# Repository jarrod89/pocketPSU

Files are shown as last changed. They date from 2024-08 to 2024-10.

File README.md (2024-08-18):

# pocketPSU

## Specs  
Output1:  
- Efuse protected USBPD output
- 3A, 20V 
- setting resolution depends on capability of USB-C brickw. If using a PPS capable supply, 10mV CV and 50mA CC settings
- By default this output is disabled as the PD command will track output 3 for minimal power loss in LDO
- Must be lower than output2  
  
Input1:
- Output1 can be used to supply pocketPSU via a battery
- Optional battery charging capability (addon board with BMS)
  
Output2:  
- (optional) Boost output with efuse protection (no dedicated CC)
- 1A 3.3-30V
- By default this tracks output3 for minimal power loss in LDO
- Must be higher than output1 and output3

Output3:  
- LDO output for low ripple
- 1A 0-30V (limited current based on input/output delta)
- Must be lower than output1

### User interface

The user interface will consist of:

- One LCD screen
- One rotary encode + integrated switch. The switch could serve as a way to switch between fine and coarse setting
- One button to turn the power output on/off
- Three buttons for navigation:
  - Up
  - Down
  - Select

### Powering the PSU

The supply can be powered over USB-C or using an external battery. The battery could potentially be a power tool battery that users already have on hand.

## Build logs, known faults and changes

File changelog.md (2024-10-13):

# Changes for hardware V2

- [ ] Move the rotary knob to another position (prevent clash with PSRAM pin)

# PD library to potentially use

- https://github.com/kcl93/fusb302_arduino

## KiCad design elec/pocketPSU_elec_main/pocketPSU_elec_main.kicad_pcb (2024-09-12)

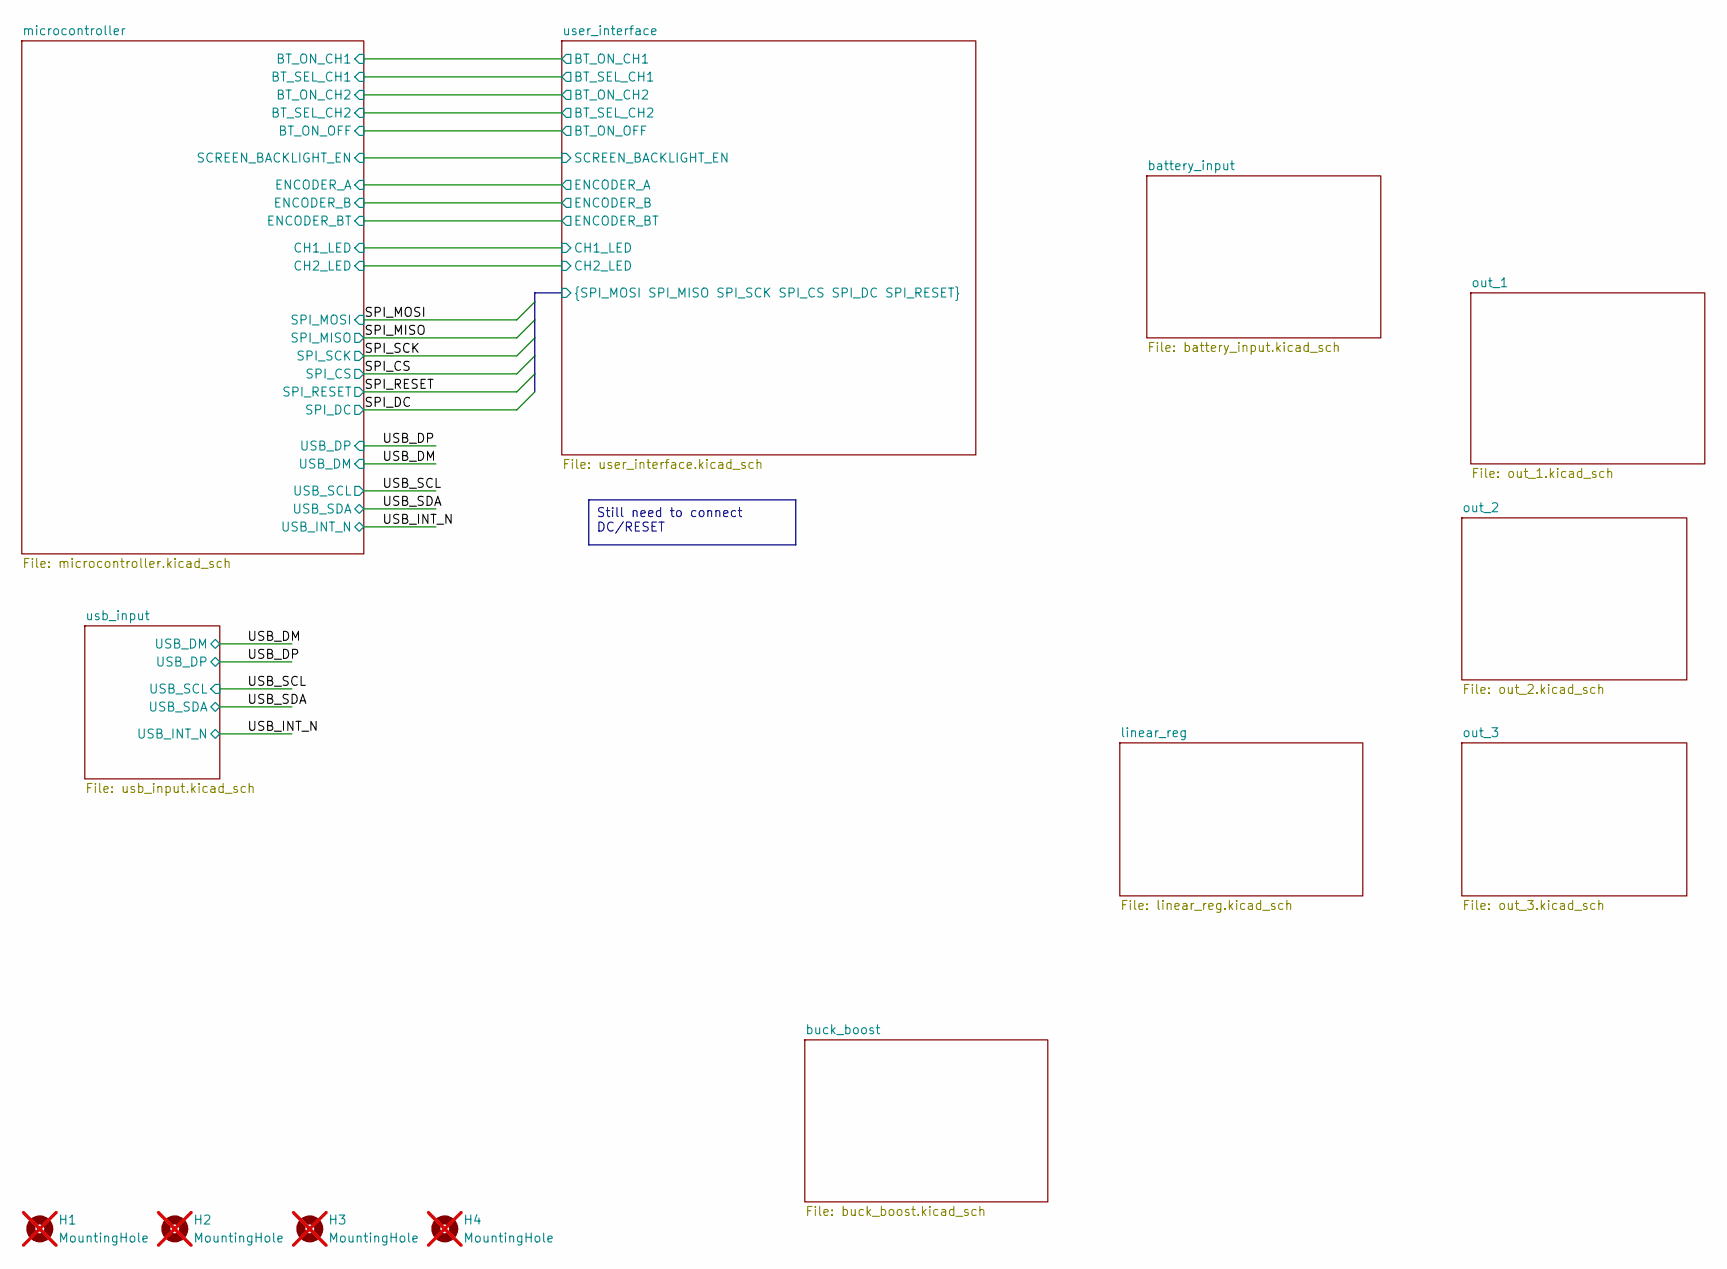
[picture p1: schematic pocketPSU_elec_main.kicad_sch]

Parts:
H1, H2, H3, H4: MountingHole; MountingHole_3.7mm_Pad_Via; not fitted

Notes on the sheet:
Still need to connect DC/RESET

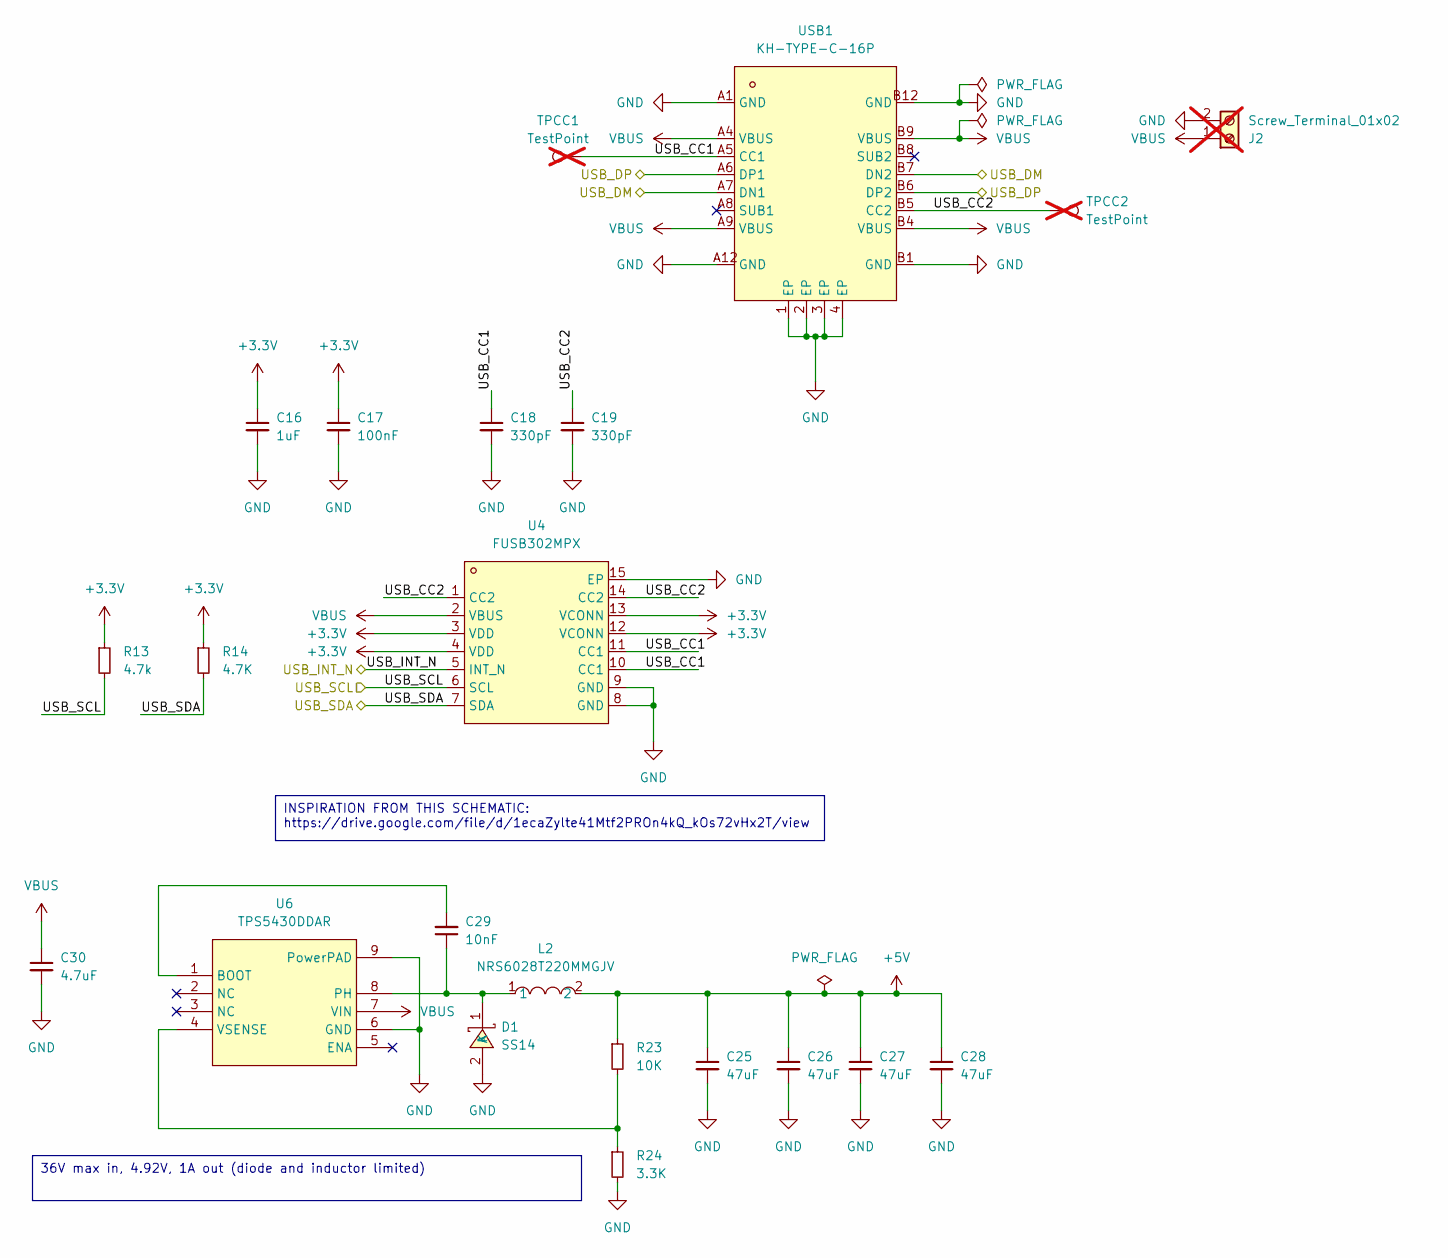
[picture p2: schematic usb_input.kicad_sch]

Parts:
C16: 1uF; C_0805_2012Metric; LCSC Part C28323
C17: 100nF; C_0805_2012Metric; LCSC Part C49678
C18, C19: 330pF; C_0603_1608Metric; LCSC Part C1664
C25, C26, C27, C28: 47uF; C_1206_3216Metric; LCSC Part C96123
C29: 10nF; C_0402_1005Metric; LCSC Part C15195
C30: 4.7uF; C_1206_3216Metric; LCSC Part C29823
D1: SS14; SMA_L4.2-W2.6-LS5.3-RD; LCSC Part C2480
J2: Screw_Terminal_01x02; TerminalBlock_Phoenix_MPT-0,5-2-2.54_1x02_P2.54mm_Horizontal; not fitted
L2: NRS6028T220MMGJV; IND-SMD_L6.0-W6.0; LCSC Part C515357
R13: 4.7k; R_0402_1005Metric; LCSC Part C25900
R14: 4.7K; R_0402_1005Metric; LCSC Part C25900
R23: 10K; R_0402_1005Metric; LCSC Part C25744
R24: 3.3K; R_0402_1005Metric; LCSC Part C25890
TPCC1, TPCC2: TestPoint; TestPoint_Pad_D1.5mm; not fitted
U4: FUSB302MPX; MLP-14_L2.5-W2.5-P0.50-BL-EP; LCSC Part C442699
U6: TPS5430DDAR; ESOP-8_L4.9-W3.9-P1.27-LS6.0-TL-EP; LCSC Part C9864
USB1: KH-TYPE-C-16P; USB-C-SMD_KH-TYPE-C-16P; LCSC Part C709357

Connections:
+3.3V: C16.1, C17.1, R13.1, R14.1, U4.3 (VDD), U4.4 (VDD), U4.12 (VCONN), U4.13 (VCONN); also elsewhere on the board
+5V: C25.1, C26.1, C27.1, C28.1, L2.2, R23.1; also elsewhere on the board
/USB_DM: USB1.A7 (DN1), USB1.B7 (DN2); also elsewhere on the board
/USB_DP: USB1.A6 (DP1), USB1.B6 (DP2); also elsewhere on the board
/USB_INT_N: U4.5 (INT_N); also elsewhere on the board
/USB_SCL: R13.2, U4.6 (SCL); also elsewhere on the board
/USB_SDA: R14.2, U4.7 (SDA); also elsewhere on the board
/usb_input/USB_CC1: C18.1, TPCC1.1, U4.10 (CC1), U4.11 (CC1), USB1.A5 (CC1)
/usb_input/USB_CC2: C19.1, TPCC2.1, U4.1 (CC2), U4.14 (CC2), USB1.B5 (CC2)
GND: C16.2, C17.2, C18.2, C19.2, C25.2, C26.2, C27.2, C28.2, C30.2, D1.2 (A), J2.2, R24.2, U4.8 (GND), U4.9 (GND), U4.15 (EP), U6.6 (GND), U6.9 (PowerPAD), USB1.1 (EP), USB1.2 (EP), USB1.3 (EP), USB1.4 (EP), USB1.A1 (GND), USB1.A12 (GND), USB1.B1 (GND), USB1.B12 (GND); also elsewhere on the board
unnamed: C29.1, D1.1 (K), L2.1, U6.8 (PH)
unnamed: C29.2, U6.1 (BOOT)
unnamed: R23.2, R24.1, U6.4 (VSENSE)
VBUS: C30.1, J2.1, U4.2 (VBUS), U6.7 (VIN), USB1.A4 (VBUS), USB1.A9 (VBUS), USB1.B4 (VBUS), USB1.B9 (VBUS)

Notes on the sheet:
36V max in, 4.92V, 1A out (diode and inductor limited)
INSPIRATION FROM THIS SCHEMATIC: https://drive.google.com/file/d/1ecaZylte41Mtf2PROn4kQ_kOs72vHx2T/view

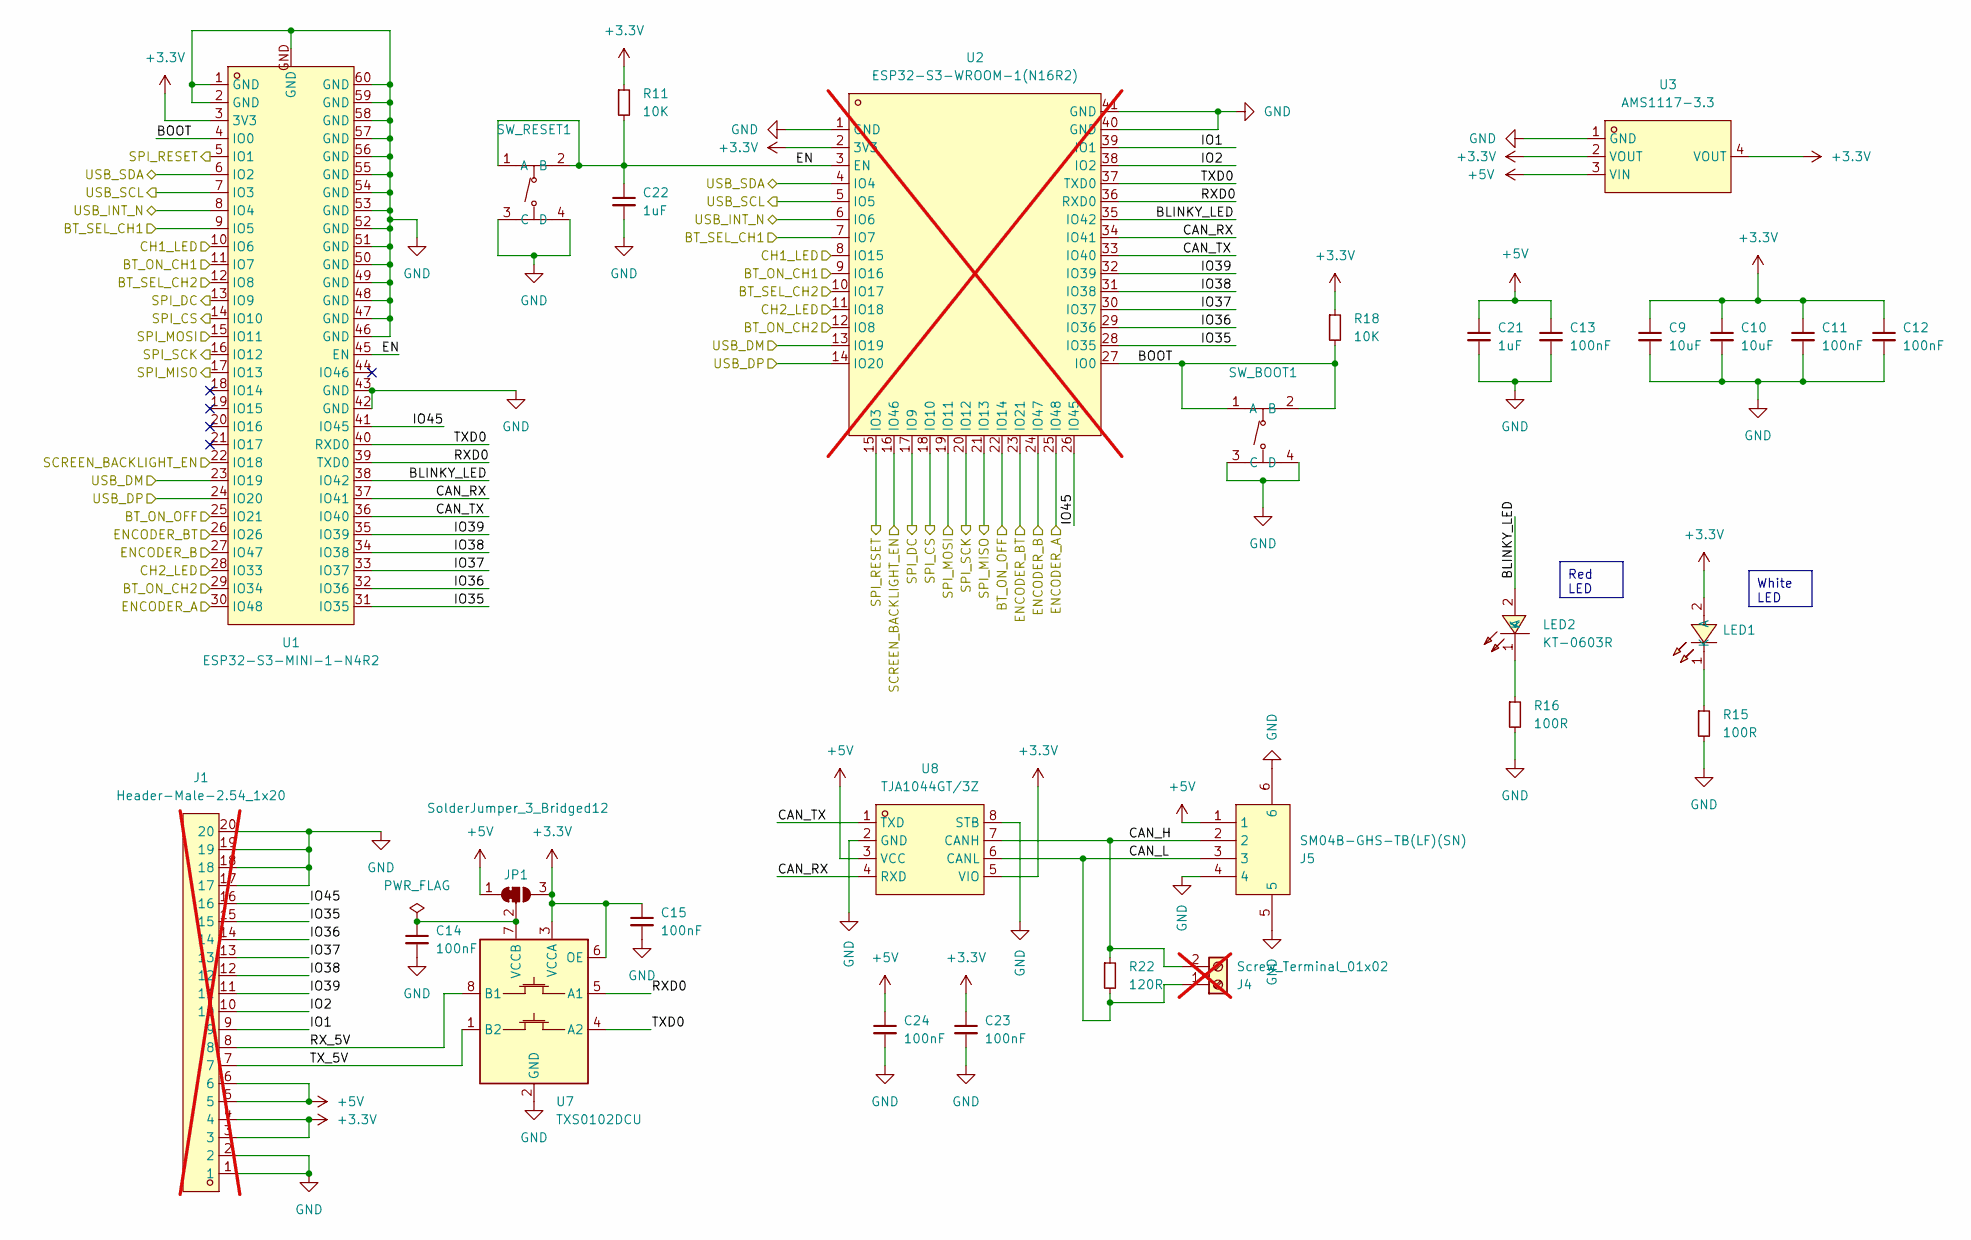
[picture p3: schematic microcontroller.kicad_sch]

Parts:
C9, C10: 10uF; C_0805_2012Metric; LCSC Part C15850
C11, C12, C13, C14, C15, C23, C24: 100nF; C_0805_2012Metric; LCSC Part C49678
C21, C22: 1uF; R_0805_2012Metric; LCSC Part C28323
J1: Header-Male-2.54_1x20; HDR-TH_20P-P2.54-V-M-1; LCSC Part C50981; not fitted
J4: Screw_Terminal_01x02; TerminalBlock_Phoenix_MPT-0,5-2-2.54_1x02_P2.54mm_Horizontal; not fitted
J5: SM04B-GHS-TB(LF)(SN); CONN-SMD_4P-P1.25_SM04B-GHS-TB-LF-SN; LCSC Part C189895
JP1: SolderJumper_3_Bridged12; SolderJumper-3_P1.3mm_Bridged12_RoundedPad1.0x1.5mm_NumberL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
LED1: F.0603.00026/P2-0603B1TS2-06T-001; LED0603-RD; LCSC Part C2290
LED2: KT-0603R; LED0603-RD; LCSC Part C2286
R11, R18: 10K; R_0402_1005Metric; LCSC Part C25744
R15, R16: 100R; R_0402_1005Metric; LCSC Part C25076
R22: 120R; R_0603_1608Metric; LCSC Part C22787
SW_BOOT1: TS-1187A-B-A-B; SW-SMD_4P-L5.1-W5.1-P3.70-LS6.5-TL-2; LCSC Part C318884
SW_RESET1: TS-1187A-B-A-B; SW-SMD_4P-L5.1-W5.1-P3.70-LS6.5-TL-2; LCSC Part C318884
U1: ESP32-S3-MINI-1-N4R2; BULETM-SMD_ESP32-S3-MINI-1-N8; LCSC Part C3013941
U2: ESP32-S3-WROOM-1(N16R2); WIRELM-SMD_ESP32-S3-WROOM-1; LCSC Part C2913205; not fitted
U3: AMS1117-3.3; SOT-223-3_L6.5-W3.4-P2.30-LS7.0-BR; LCSC Part C6186
U7: TXS0102DCU; VSSOP-8_2.3x2mm_P0.5mm; LCSC Part C53434
U8: TJA1044GT/3Z; SO-8_L4.9-W3.9-P1.27-LS5.9-BL; LCSC Part C961486

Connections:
+3.3V: C9.1, C10.1, C11.1, C12.1, C15.1, C23.1, J1.3, J1.4, JP1.3 (B), LED1.2 (A), R11.1, R18.1, U1.3 (3V3), U2.2 (3V3), U3.2 (VOUT), U3.4 (VOUT), U7.3 (VCCA), U7.6 (OE), U8.5 (VIO); also elsewhere on the board
+5V: C13.1, C21.1, C24.1, J1.5, J1.6, J5.1, JP1.1 (A), U3.3 (VIN), U8.3 (VCC); also elsewhere on the board
/USB_DM: U1.23 (IO19), U2.13 (IO19); also elsewhere on the board
/USB_DP: U1.24 (IO20), U2.14 (IO20); also elsewhere on the board
/USB_INT_N: U1.8 (IO4), U2.6 (IO6); also elsewhere on the board
/USB_SCL: U1.7 (IO3), U2.5 (IO5); also elsewhere on the board
/USB_SDA: U1.6 (IO2), U2.4 (IO4); also elsewhere on the board
/microcontroller/BLINKY_LED: LED2.2 (A), U1.38 (IO42), U2.35 (IO42)
/microcontroller/BOOT: R18.2, SW_BOOT1.1 (A), SW_BOOT1.2 (B), U1.4 (IO0), U2.27 (IO0)
/microcontroller/BT_ON_CH1: U1.11 (IO7), U2.9 (IO16); also elsewhere on the board
/microcontroller/BT_ON_CH2: U1.29 (IO34), U2.12 (IO8); also elsewhere on the board
/microcontroller/BT_ON_OFF: U1.25 (IO21), U2.22 (IO14); also elsewhere on the board
/microcontroller/BT_SEL_CH1: U1.9 (IO5), U2.7 (IO7); also elsewhere on the board
/microcontroller/BT_SEL_CH2: U1.12 (IO8), U2.10 (IO17); also elsewhere on the board
/microcontroller/CAN_H: J4.2, J5.2, R22.1, U8.7 (CANH)
/microcontroller/CAN_L: J4.1, J5.3, R22.2, U8.6 (CANL)
/microcontroller/CAN_RX: U1.37 (IO41), U2.34 (IO41), U8.4 (RXD)
/microcontroller/CAN_TX: U1.36 (IO40), U2.33 (IO40), U8.1 (TXD)
/microcontroller/CH1_LED: U1.10 (IO6), U2.8 (IO15); also elsewhere on the board
/microcontroller/CH2_LED: U1.28 (IO33), U2.11 (IO18); also elsewhere on the board
/microcontroller/EN: C22.1, R11.2, SW_RESET1.1 (A), SW_RESET1.2 (B), U1.45 (EN), U2.3 (EN)
/microcontroller/ENCODER_A: U1.30 (IO48), U2.25 (IO48); also elsewhere on the board
/microcontroller/ENCODER_B: U1.27 (IO47), U2.24 (IO47); also elsewhere on the board
/microcontroller/ENCODER_BT: U1.26 (IO26), U2.23 (IO21); also elsewhere on the board
/microcontroller/IO1: J1.9, U2.39 (IO1)
/microcontroller/IO2: J1.10, U2.38 (IO2)
/microcontroller/IO35: J1.15, U1.31 (IO35), U2.28 (IO35)
/microcontroller/IO36: J1.14, U1.32 (IO36), U2.29 (IO36)
/microcontroller/IO37: J1.13, U1.33 (IO37), U2.30 (IO37)
/microcontroller/IO38: J1.12, U1.34 (IO38), U2.31 (IO38)
/microcontroller/IO39: J1.11, U1.35 (IO39), U2.32 (IO39)
/microcontroller/IO45: J1.16, U1.41 (IO45), U2.26 (IO45)
/microcontroller/RXD0: U1.39 (TXD0), U2.36 (RXD0), U7.5 (A1)
/microcontroller/RX_5V: J1.8, U7.8 (B1)
/microcontroller/TXD0: U1.40 (RXD0), U2.37 (TXD0), U7.4 (A2)
/microcontroller/TX_5V: J1.7, U7.1 (B2)
/user_interface/BACKLIGHT_EN: U1.22 (IO18), U2.16 (IO46); also elsewhere on the board
/user_interface/SPI_CS: U1.14 (IO10), U2.18 (IO10); also elsewhere on the board
/user_interface/SPI_DC: U1.13 (IO9), U2.17 (IO9); also elsewhere on the board
/user_interface/SPI_MISO: U1.17 (IO13), U2.21 (IO13); also elsewhere on the board
/user_interface/SPI_MOSI: U1.15 (IO11), U2.19 (IO11); also elsewhere on the board
/user_interface/SPI_RESET: U1.5 (IO1), U2.15 (IO3); also elsewhere on the board
/user_interface/SPI_SCK: U1.16 (IO12), U2.20 (IO12); also elsewhere on the board
GND: C9.2, C10.2, C11.2, C12.2, C13.2, C14.2, C15.2, C21.2, C22.2, C23.2, C24.2, J1.1, J1.2, J1.17, J1.18, J1.19, J1.20, J5.4, J5.5, J5.6, R15.2, R16.2, SW_BOOT1.3 (C), SW_BOOT1.4 (D), SW_RESET1.3 (C), SW_RESET1.4 (D), U1.1 (GND), U1.2 (GND), U1.42 (GND), U1.43 (GND), U1.46 (GND), U1.47 (GND), U1.48 (GND), U1.49 (GND), U1.50 (GND), U1.51 (GND), U1.52 (GND), U1.53 (GND), U1.54 (GND), U1.55 (GND), U1.56 (GND), U1.57 (GND), U1.58 (GND), U1.59 (GND), U1.60 (GND), U1.GND, U2.1 (GND), U2.40 (GND), U2.41 (GND), U3.1 (GND), U7.2 (GND), U8.2 (GND), U8.8 (STB); also elsewhere on the board
unnamed: C14.1, JP1.2 (C), U7.7 (VCCB)
unnamed: LED1.1 (K), R15.1
unnamed: LED2.1 (K), R16.1

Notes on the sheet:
White LED
Red LED

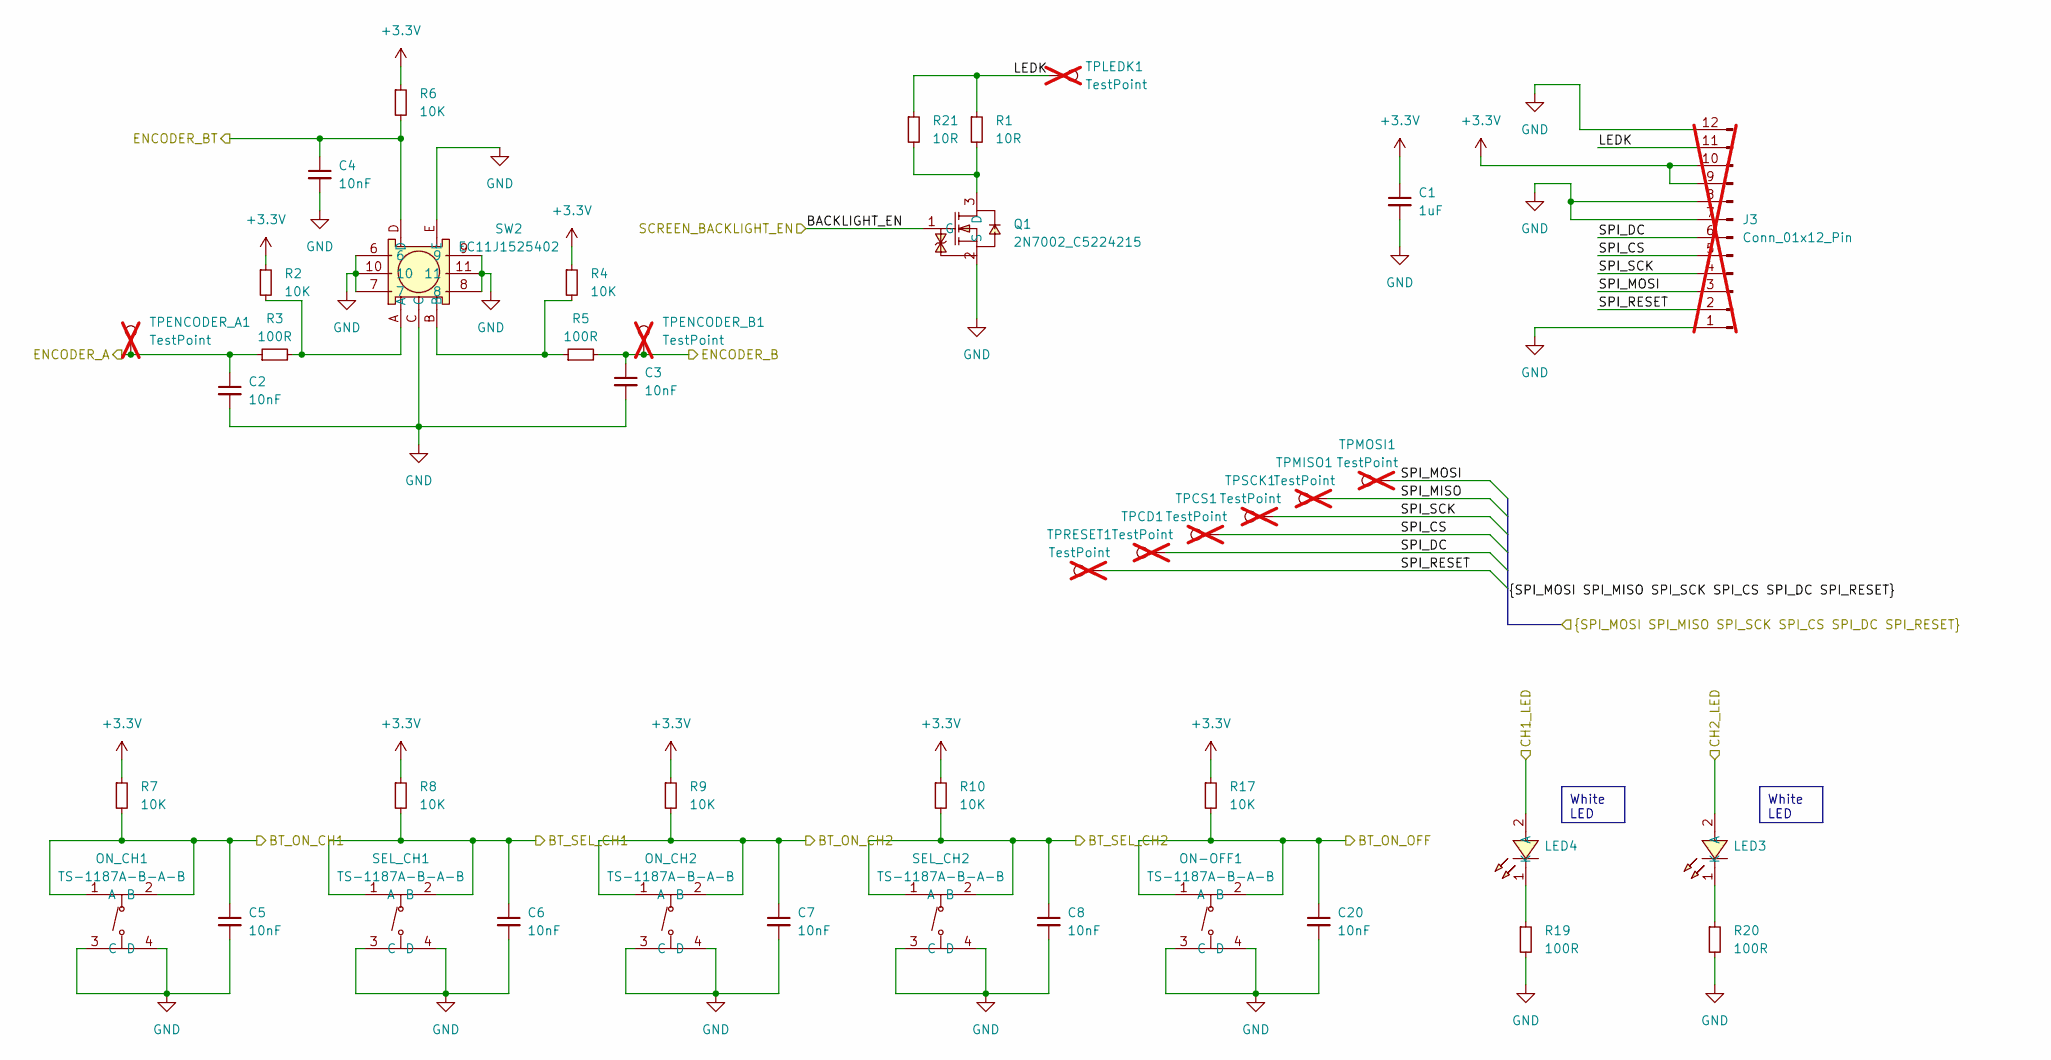
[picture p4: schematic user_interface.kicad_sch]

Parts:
C1: 1uF; R_0805_2012Metric; LCSC Part C28323
C2, C3, C4, C5, C6, C7, C8, C20: 10nF; C_0402_1005Metric; LCSC Part C15195
J3: Conn_01x12_Pin; LCD-GMT020-02; not fitted
LED3, LED4: F.0603.00026/P2-0603B1TS2-06T-001; LED0603-RD; LCSC Part C2290
ON-OFF1: TS-1187A-B-A-B; SW-SMD_4P-L5.1-W5.1-P3.70-LS6.5-TL-2; LCSC Part C318884
ON_CH1, ON_CH2: TS-1187A-B-A-B; SW-SMD_4P-L5.1-W5.1-P3.70-LS6.5-TL-2; LCSC Part C318884
Q1: 2N7002_C5224215; SOT-23-3_L3.0-W1.6-P1.90-LS2.8-BR; LCSC Part C5224215
R1, R21: 10R; R_0402_1005Metric; LCSC Part C25077
R2, R4, R6, R7, R8, R9, R10, R17: 10K; R_0402_1005Metric; LCSC Part C25744
R3, R5, R19, R20: 100R; R_0402_1005Metric; LCSC Part C25076
SEL_CH1, SEL_CH2: TS-1187A-B-A-B; SW-SMD_4P-L5.1-W5.1-P3.70-LS6.5-TL-2; LCSC Part C318884
SW2: EC11J1525402; SW-SMD_EC11J1525402; LCSC Part C209762
TPCD1: TestPoint; TestPoint_Pad_D1.5mm; not fitted
TPCS1: TestPoint; TestPoint_Pad_D1.5mm; not fitted
TPENCODER_A1: TestPoint; TestPoint_Pad_D1.5mm; not fitted
TPENCODER_B1: TestPoint; TestPoint_Pad_D1.5mm; not fitted
TPLEDK1: TestPoint; TestPoint_Pad_D1.5mm; not fitted
TPMISO1: TestPoint; TestPoint_Pad_D1.5mm; not fitted
TPMOSI1: TestPoint; TestPoint_Pad_D1.5mm; not fitted
TPRESET1: TestPoint; TestPoint_Pad_D1.5mm; not fitted
TPSCK1: TestPoint; TestPoint_Pad_D1.5mm; not fitted

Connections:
+3.3V: C1.1, J3.9, J3.10, R2.1, R4.1, R6.1, R7.1, R8.1, R9.1, R10.1, R17.1; also elsewhere on the board
/microcontroller/BT_ON_CH1: C5.1, ON_CH1.1 (A), ON_CH1.2 (B), R7.2; also elsewhere on the board
/microcontroller/BT_ON_CH2: C7.1, ON_CH2.1 (A), ON_CH2.2 (B), R9.2; also elsewhere on the board
/microcontroller/BT_ON_OFF: C20.1, ON-OFF1.1 (A), ON-OFF1.2 (B), R17.2; also elsewhere on the board
/microcontroller/BT_SEL_CH1: C6.1, R8.2, SEL_CH1.1 (A), SEL_CH1.2 (B); also elsewhere on the board
/microcontroller/BT_SEL_CH2: C8.1, R10.2, SEL_CH2.1 (A), SEL_CH2.2 (B); also elsewhere on the board
/microcontroller/CH1_LED: LED4.2 (A); also elsewhere on the board
/microcontroller/CH2_LED: LED3.2 (A); also elsewhere on the board
/microcontroller/ENCODER_A: C2.1, R3.1, TPENCODER_A1.1; also elsewhere on the board
/microcontroller/ENCODER_B: C3.1, R5.2, TPENCODER_B1.1; also elsewhere on the board
/microcontroller/ENCODER_BT: C4.1, R6.2, SW2.D; also elsewhere on the board
/user_interface/BACKLIGHT_EN: Q1.1 (G); also elsewhere on the board
/user_interface/LEDK: J3.11, R1.1, R21.1, TPLEDK1.1
/user_interface/SPI_CS: J3.5, TPCS1.1; also elsewhere on the board
/user_interface/SPI_DC: J3.6, TPCD1.1; also elsewhere on the board
/user_interface/SPI_MISO: TPMISO1.1; also elsewhere on the board
/user_interface/SPI_MOSI: J3.3, TPMOSI1.1; also elsewhere on the board
/user_interface/SPI_RESET: J3.2, TPRESET1.1; also elsewhere on the board
/user_interface/SPI_SCK: J3.4, TPSCK1.1; also elsewhere on the board
GND: C1.2, C2.2, C3.2, C4.2, C5.2, C6.2, C7.2, C8.2, C20.2, J3.1, J3.7, J3.8, J3.12, ON-OFF1.3 (C), ON-OFF1.4 (D), ON_CH1.3 (C), ON_CH1.4 (D), ON_CH2.3 (C), ON_CH2.4 (D), Q1.2 (S), R19.2, R20.2, SEL_CH1.3 (C), SEL_CH1.4 (D), SEL_CH2.3 (C), SEL_CH2.4 (D), SW2.6, SW2.7, SW2.8, SW2.9, SW2.10, SW2.11, SW2.C, SW2.E; also elsewhere on the board
unnamed: LED3.1 (K), R20.1
unnamed: LED4.1 (K), R19.1
unnamed: Q1.3 (D), R1.2, R21.2
unnamed: R2.2, R3.2, SW2.A
unnamed: R4.2, R5.1, SW2.B

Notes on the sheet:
White LED

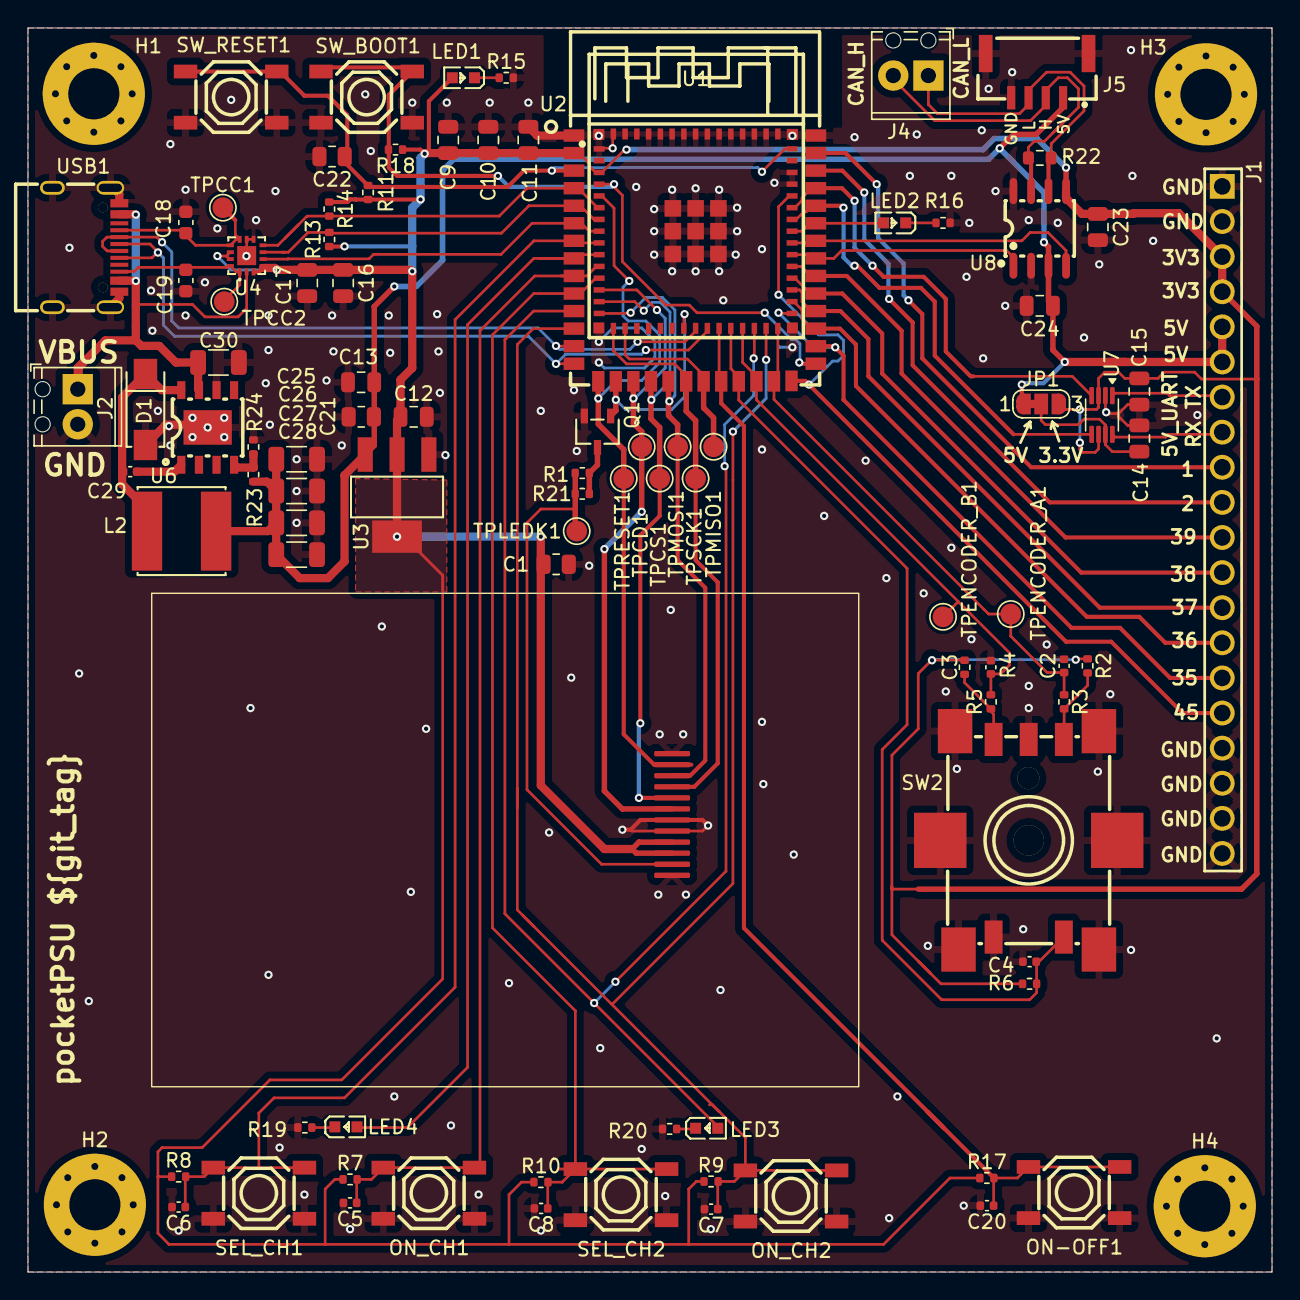
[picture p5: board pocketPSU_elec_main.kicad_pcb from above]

Board: 2 copper layers, 90.0 x 90.0 mm, 97 parts (0 on the bottom side), 59 nets.

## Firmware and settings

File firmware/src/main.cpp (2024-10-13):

#include <Arduino.h>
#include <ESP32-TWAI-CAN.hpp>
#include <lvgl.h>
#if LV_USE_TFT_ESPI
#include <TFT_eSPI.h>
#endif

#include <Wire.h>
#include <PD_UFP.h>

#define PIN_FUSB302_INT   4

class PD_UFP_Log_c PD_UFP;

#define SERIAL_DEBUG 1

#include "StateMachine.hpp"

#define TFT_HOR_RES   240
#define TFT_VER_RES   320
#define TFT_ROTATION  LV_DISPLAY_ROTATION_270

#define SDA_PIN 2
#define SCL_PIN 3


// /*LVGL draw into this buffer, 1/10 screen size usually works well. The size is in bytes*/
// #define DRAW_BUF_SIZE (TFT_HOR_RES * TFT_VER_RES / 10 * (LV_COLOR_DEPTH / 8))
// uint32_t draw_buf[DRAW_BUF_SIZE / 4];

// /* LVGL calls it when a rendered image needs to copied to the display*/
// void my_disp_flush( lv_display_t *disp, const lv_area_t *area, uint8_t * px_map)
// {
//     /*Call it to tell LVGL you are ready*/
//     lv_display_flush_ready(disp);
// }

// /*use Arduinos millis() as tick source*/
// static uint32_t my_tick(void)
// {
//     return millis();
// }


// StateMachine state_machine;

// float voltage_limit_ch1;
// float current_limit_ch1;
// float voltage_limit_ch2;
// float current_limit_ch2;
// float voltage_ch1;
// float current_ch1;
// float power_ch1;
// float voltage_ch2;
// float current_ch2;
// float power_ch2;

// lv_obj_t *voltage_limit_ch1_label;
// lv_obj_t *current_limit_ch1_label;
// lv_obj_t *voltage_limit_ch2_label;
// lv_obj_t *current_limit_ch2_label;
// lv_obj_t *voltage_ch1_label;
// lv_obj_t *current_ch1_label;
// lv_obj_t *power_ch1_label;
// lv_obj_t *voltage_ch2_label;
// lv_obj_t *current_ch2_label;
// lv_obj_t *power_ch2_label;

// static lv_style_t style_normal;
// static lv_style_t style_active;


// volatile long encoderCtr = 0;

// void handleEncoder() {
//     if(digitalRead(ENCODER_A))
//     {
//         if(digitalRead(ENCODER_B))
//         encoderCtr++;
//         else
//         encoderCtr--;
//     }
//     else
//     {
//         if(digitalRead(ENCODER_B))
//         encoderCtr--;
//         else
//         encoderCtr++;
//     }
// }
// volatile unsigned long lastDebounceTimeCh1Set = 0;  // Variables to store last debounce time
// volatile unsigned long lastDebounceTimeCh2Set = 0;
// volatile unsigned long lastDebounceTimeCh1On = 0;
// volatile unsigned long lastDebounceTimeCh2On = 0;
// volatile unsigned long lastDebounceTimeOnOff = 0;

// const unsigned long debounceDelay = 200;  // Set debounce delay to 50ms

// void handleCh1SetBt() {
//     if ((millis() - lastDebounceTimeCh1Set) > debounceDelay) {
//         lastDebounceTimeCh1Set = millis();  // Update last debounce time
//         state_machine.handleCh1SetBt();  // Your existing function
//     }
// }

// void handleCh2SetBt() {
//     if ((millis() - lastDebounceTimeCh2Set) > debounceDelay) {
//         lastDebounceTimeCh2Set = millis();
//         state_machine.handleCh2SetBt();
//     }
// }

// void handleCh1OnBt() {
//     if ((millis() - lastDebounceTimeCh1On) > debounceDelay) {
//         lastDebounceTimeCh1On = millis();
//         state_machine.handleCh1OnBt();  // Call your state handling logic
//     }
// }

// void handleCh2OnBt() {
//     if ((millis() - lastDebounceTimeCh2On) > debounceDelay) {
//         lastDebounceTimeCh2On = millis();
//         state_machine.handleCh2OnBt();
//     }
// }

// void handleOnOffBt() {
//     if ((millis() - lastDebounceTimeOnOff) > debounceDelay) {
//         lastDebounceTimeOnOff = millis();
//         digitalWrite(LED_RED, !digitalRead(LED_RED));  // Toggle LED state
//     }
// }

// // void handleKnobBt() {
// //     digitalWrite(LED_RED, !digitalRead(LED_RED));  // Toggle LED state
// // }

// void highlight_active_label(lv_obj_t *label) {
//   // Apply the active style (black background, white text)
//   lv_obj_add_style(label, &style_active, LV_PART_MAIN);
// }

// // remove the highlight after update
// void remove_highlights() {
//     lv_obj_add_style(voltage_limit_ch1_label, &style_normal, LV_PART_MAIN);
//     lv_obj_add_style(current_limit_ch1_label, &style_normal, LV_PART_MAIN);
//     lv_obj_add_style(voltage_limit_ch2_label, &style_normal, LV_PART_MAIN);
//     lv_obj_add_style(current_limit_ch2_label, &style_normal, LV_PART_MAIN);
// }



void setup() {
    pinMode(LED_RED, OUTPUT);
    digitalWrite(LED_RED, 1);
    delay(100);
    // pinMode(LED_CH1, OUTPUT);
    // pinMode(LED_CH2, OUTPUT);

    // pinMode(CH_1_SET_BT, INPUT_PULLUP);
    // pinMode(CH_2_SET_BT, INPUT_PULLUP);
    // pinMode(CH_1_ON_BT, INPUT_PULLUP);
    // pinMode(CH_2_ON_BT, INPUT_PULLUP);
    // pinMode(ALL_ON_OFF, INPUT_PULLUP);
    // // pinMode(KNOB_BT, INPUT);
    // pinMode(ENCODER_A, INPUT);
    // pinMode(ENCODER_B, INPUT);
    // attachInterrupt(digitalPinToInterrupt(ENCODER_A), handleEncoder,CHANGE);
    // attachInterrupt(digitalPinToInterrupt(CH_1_SET_BT), handleCh1SetBt, FALLING);
    // attachInterrupt(digitalPinToInterrupt(CH_2_SET_BT), handleCh2SetBt, FALLING);
    // attachInterrupt(digitalPinToInterrupt(CH_1_ON_BT), handleCh1OnBt, FALLING);
    // attachInterrupt(digitalPinToInterrupt(CH_2_ON_BT), handleCh2OnBt, FALLING);
    // attachInterrupt(digitalPinToInterrupt(ALL_ON_OFF), handleOnOffBt, FALLING);
    // attachInterrupt(digitalPinToInterrupt(KNOB_BT), handleKnobBt, FALLING);

    #if SERIAL_DEBUG
    // Setup serial for debbuging.
    Serial.begin(115200);
    // tft.println("Hello World!");
    Serial.println("Hello World!");
    #endif

    // Setup UART0 for debugging
    Serial0.begin(115200);
    Serial0.println("Startup");

    Wire.begin(SDA_PIN, SCL_PIN, 100000);
    PD_UFP.init(PIN_FUSB302_INT, PD_POWER_OPTION_MAX_9V);
    // PD_UFP.init_PPS(PIN_FUSB302_INT, PPS_V(5.5), PPS_A(.5));
    PD_UFP.init_PPS(PIN_FUSB302_INT, PPS_V(9.0), PPS_A(5.0));

    // // //Initialize the LVGL library
    // lv_init();

    // /*Set a tick source so that LVGL will know how much time elapsed. */
    // lv_tick_set_cb(my_tick);

    // lv_style_init(&style_normal);
    // lv_style_set_bg_opa(&style_normal, LV_OPA_TRANSP);  // No background
    // lv_style_set_text_color(&style_normal, lv_color_hex(0x000000));  // White text

    // lv_style_init(&style_active);
    // lv_style_set_bg_opa(&style_active, LV_OPA_COVER);  // Opaque background
    // lv_style_set_bg_color(&style_active, lv_color_hex(0x000000));  // Black background
    // lv_style_set_text_color(&style_active, lv_color_hex(0xFFFFFF));  // White text

    // // alternative function: lv_obj_set_style_text_color(thing, lv_color_black(), LV_PART_MAIN);


    // lv_display_t * disp;
    // /*TFT_eSPI can be enabled lv_conf.h to initialize the display in a simple way*/
    // disp = lv_tft_espi_create(TFT_HOR_RES, TFT_VER_RES, draw_buf, sizeof(draw_buf));
    // lv_display_set_rotation(disp, TFT_ROTATION);

    // // Initialize the labels on screen
    // // CH1
    // voltage_ch1_label = lv_label_create(lv_scr_act());
    // lv_label_set_text_fmt(voltage_ch1_label, "%.3fV", voltage_ch1);
    // lv_obj_align(voltage_ch1_label, LV_ALIGN_TOP_LEFT, 10, 50);

    // current_ch1_label = lv_label_create(lv_scr_act());
    // lv_label_set_text_fmt(current_ch1_label, "%.3fV", current_ch1);
    // lv_obj_align(current_ch1_label, LV_ALIGN_TOP_LEFT, 10, 80);

    // lv_obj_t *set_txt_ch1 = lv_label_create(lv_scr_act());
    // lv_label_set_text(set_txt_ch1, "set");
    // lv_obj_align(set_txt_ch1, LV_ALIGN_TOP_LEFT, 5, 200);

    // voltage_limit_ch1_label = lv_label_create(lv_scr_act());
    // lv_label_set_text_fmt(voltage_limit_ch1_label, "%fV", voltage_limit_ch1);
    // lv_obj_align(voltage_limit_ch1_label, LV_ALIGN_TOP_LEFT, 30, 200);

    // current_limit_ch1_label = lv_label_create(lv_scr_act());
    // lv_label_set_text_fmt(current_limit_ch1_label, "%fA", current_limit_ch1);
    // lv_obj_align(current_limit_ch1_label, LV_ALIGN_TOP_LEFT, 90, 200);

    // // CH2

    // voltage_ch2_label = lv_label_create(lv_scr_act());
    // lv_label_set_text_fmt(voltage_ch2_label, "%fV", voltage_ch2);
    // lv_obj_align(voltage_ch2_label, LV_ALIGN_TOP_LEFT, 170, 50);

    // current_ch2_label = lv_label_create(lv_scr_act());
    // lv_label_set_text_fmt(current_ch2_label, "%fV", current_ch2);
    // lv_obj_align(current_ch2_label, LV_ALIGN_TOP_LEFT, 170, 80);

    // lv_obj_t *set_txt_ch2 = lv_label_create(lv_scr_act());
    // lv_label_set_text(set_txt_ch2, "set");
    // lv_obj_align(set_txt_ch2, LV_ALIGN_TOP_LEFT, 165, 200);

    // voltage_limit_ch2_label = lv_label_create(lv_scr_act());
    // lv_label_set_text_fmt(voltage_limit_ch2_label, "%fV", voltage_limit_ch2);
    // lv_obj_align(voltage_limit_ch2_label, LV_ALIGN_TOP_LEFT, 190, 200);  // Position the label

    // current_limit_ch2_label = lv_label_create(lv_scr_act());
    // lv_label_set_text_fmt(current_limit_ch2_label, "%fA", current_limit_ch2);
    // lv_obj_align(current_limit_ch2_label, LV_ALIGN_TOP_LEFT, 250, 200);  // Position the label

    // // CH2

    // voltage_limit_ch2_label = lv_label_create(lv_scr_act());
    // lv_label_set_text_fmt(voltage_limit_ch2_label, "Voltage ch2: %d V", voltage_limit_ch2);
    // lv_obj_align(voltage_limit_ch2_label, LV_ALIGN_TOP_LEFT, 160, 10);  // Position the label

    // current_limit_ch2_label = lv_label_create(lv_scr_act());
    // lv_label_set_text_fmt(current_limit_ch2_label, "Current ch2: %d A", current_limit_ch2);
    // lv_obj_align(current_limit_ch2_label, LV_ALIGN_TOP_LEFT, 160, 40);  // Position the label
}

void loop() {

    // StateStruct currentState = state_machine.getState();
    // switch (currentState.settingState) {
    //     case SettingState::IDLE:
    //         #if SERIAL_DEBUG
    //         Serial.println("IDLE");
    //         #endif
    //         // flush the encoder values
    //         encoderCtr = 0;
    //         remove_highlights();
    //         break;
    //     case SettingState::SET_VOLTAGE_CH_1:
    //         #if SERIAL_DEBUG
    //         Serial.print("SET_VOLTAGE_CH_1: ");
    //         Serial.println(voltage_limit_ch1);
    //         #endif
    //         voltage_limit_ch1 += encoderCtr;
    //         encoderCtr = 0;
    //         remove_highlights();
    //         highlight_active_label(voltage_limit_ch1_label);
    //         break;
    //     case SettingState::SET_CURRENT_CH_1:
    //         #if SERIAL_DEBUG
    //         Serial.print("SET_CURRENT_CH_1: ");
    //         Serial.println(current_limit_ch1);
    //         #endif
    //         current_limit_ch1 += encoderCtr;
    //         encoderCtr = 0;
    //         remove_highlights();
    //         highlight_active_label(current_limit_ch1_label);
    //         break;
    //     case SettingState::SET_VOLTAGE_CH_2:
    //         #if SERIAL_DEBUG
    //         Serial.print("SET_VOLTAGE_CH_2: ");
    //         Serial.println(voltage_limit_ch2);
    //         #endif
    //         voltage_limit_ch2 += encoderCtr;
    //         encoderCtr = 0;
    //         remove_highlights();
    //         highlight_active_label(voltage_limit_ch2_label);
    //         break;
    //     case SettingState::SET_CURRENT_CH_2:
    //         #if SERIAL_DEBUG
    //         Serial.print("SET_CURRENT_CH_2: ");
    //         Serial.println(current_limit_ch2);
    //         #endif
    //         current_limit_ch2 += encoderCtr;
    //         encoderCtr = 0;
    //         remove_highlights();
    //         highlight_active_label(current_limit_ch2_label);
    //         break;
    // }
    // switch (currentState.channel1State) {
    //     case ChannelState::IDLE:
    //         digitalWrite(LED_CH1, LOW);
    //         break;
    //     case ChannelState::ON:
    //         digitalWrite(LED_CH1, HIGH);
    //         break;
    // }
    // switch (currentState.channel2State) {
    //     case ChannelState::IDLE:
    //         digitalWrite(LED_CH2, LOW);
    //         break;
    //     case ChannelState::ON:
    //         digitalWrite(LED_CH2, HIGH);
    //         break;
    // }
    // lv_label_set_text_fmt(voltage_limit_ch1_label, "%.3fV", voltage_limit_ch1);
    // lv_label_set_text_fmt(current_limit_ch1_label, "%.3fA", current_limit_ch1);
    // lv_label_set_text_fmt(voltage_limit_ch2_label, "%.3fV", voltage_limit_ch2);
    // lv_label_set_text_fmt(current_limit_ch2_label, "%.3fA", current_limit_ch2);
    // lv_timer_handler(); /* let the GUI do its work */

    PD_UFP.run();
    static int pd_status = 0;
    // // Serial0.println("run");
    PD_UFP.print_status(Serial0);
    if (PD_UFP.is_PPS_ready())
    {
      if (pd_status != 1){
      pd_status = 1;
      Serial0.println("PPS trigger success");
      }
    }
    else if (PD_UFP.is_power_ready())
    {
      if (pd_status != 2){
      pd_status = 2;
      Serial0.println("Fail to trigger PPS, fall back");
      }
    }
    else
    {
      if (pd_status != 3){
      pd_status = 3;
      Serial0.println("PD not ready");
      }
    }
    //delay(10);
    digitalWrite(LED_RED, !digitalRead(LED_RED));  // Toggle LED state  
}

float mapValue(float ip, float ipmin, float ipmax, float tomin, float tomax)
{
    return tomin + (((tomax - tomin) * (ip - ipmin))/ (ipmax - ipmin));
}

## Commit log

2024-08-07 add early electrical architecture
    [battery_input.kicad_sch, buck_boost.kicad_sch, linear_reg.kicad_sch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]
2024-08-07 part selection spreadsheet
    [part_selection.xlsx]
2024-08-08 added user interface elements
    [pocketPSU_elec_main.kicad_pcb, pocketPSU_elec_main.kicad_sch, user_interface.kicad_sch]
2024-08-08 add button, deglitch
    [user_interface.kicad_sch]
2024-08-08 lad into layout
    [pocketPSU_elec_main.kicad_pcb]
2024-08-08 add value to bypass cap
    [user_interface.kicad_sch]
2024-08-09 add esp32 micro
    [microcontroller.kicad_sch, pocketPSU_elec_main.kicad_sch, usb_input.kicad_sch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]
2024-08-10 Add footprints, change TFT hookup
    [microcontroller.kicad_sch, pocketPSU_elec_main.kicad_pcb, pocketPSU_elec_main.kicad_sch]
2024-08-10 preliminary layout
    [pocketPSU_elec_main.kicad_pcb, usb_input.kicad_sch, user_interface.kicad_sch]
2024-08-13 add usb coms chip
    [microcontroller.kicad_sch, pocketPSU_elec_main.kicad_sch, usb_input.kicad_sch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]
2024-08-13 add bypass caps on usb coms chip
    [usb_input.kicad_sch]
2024-08-13 fix caps values, rework layout
    [microcontroller.kicad_sch, pocketPSU_elec_main.kicad_pcb, usb_input.kicad_sch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]
2024-08-13 add copper fill
    [pocketPSU_elec_main.kicad_pcb, usb_input.kicad_sch, user_interface.kicad_sch]
2024-08-13 route traces and add gnd pour
    [pocketPSU_elec_main.kicad_pcb]
2024-08-14 add boot switch and test points
    [microcontroller.kicad_sch, pocketPSU_elec_main.kicad_pcb]
2024-08-19 add buttons and leds for on/off indication
    [microcontroller.kicad_sch, pocketPSU_elec_main.kicad_pcb, pocketPSU_elec_main.kicad_sch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]
2024-08-23 move components, add mounting holes
    [pocketPSU_elec_main.kicad_pcb, pocketPSU_elec_main.kicad_sch]
2024-09-01 move pullup nodes, change to 2.54mm header
    [microcontroller.kicad_sch, user_interface.kicad_sch]
2024-09-01 board routed
    [microcontroller.kicad_sch, pocketPSU_elec_main.kicad_pcb]
2024-09-01 add groud vias
    [pocketPSU_elec_main.kicad_pcb]
2024-09-01 fix some drcs
    [pocketPSU_elec_main.kicad_pcb]
2024-09-01 fix schematic
    [pocketPSU_elec_main.kicad_sch]
2024-09-11 Cleanup, Buck, CAN (#6)
    * mid-layout
    * finished routing
    * Kibot (#7)
    Add kibot with JLC output generation
    * fix 3d, add drc
    * fix erc
    * fix pcb drc
    * drc ignore_unconnected
    * attempt to add githash and tag
    * add silk githash string
    * add silk tag string
    * change outputs
    ---------
    [battery_input.kicad_sch, buck_boost.kicad_sch, linear_reg.kicad_sch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]
2024-09-11 fix kibot (#8)
    * remove 3d and pcb prints
    * ctrl-z
    * clean up kibot
    * add 3d render
    * add 3d render and make it run
    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
2024-09-12 Add mini esp32 module, smd rotary encoder and leds
    [microcontroller.kicad_sch, pocketPSU_elec_main.kicad_pcb, user_interface.kicad_sch]
2024-09-12 fix DRC errors (#9)
    * nop
    * add erc flags to unconnected pins
    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
    [microcontroller.kicad_sch, pocketPSU_elec_main.kicad_pcb]
2024-10-13 Esp fw (#10)
    * add platformio project with lcd demo
    * wip: add config for rp2040 with basic state machine
    * add blinky debug, memory csv and comment out pico build
    * play with encoder library
    * manual interrupt based encoder logic. fun meter on LCD
    * moved pin definitions to platformio.ini so it compiles on pico again
    * play with lvgl
    * "deep+" option to resolve dependency graph was causing issues. Switched to "deep"
    * shuffling values on screen + cleanup
    * remove printf
    * bricked
    * first stab at usb coms
    * checkpoint
    * move to platformio library for fusb302, use uart0 for debug
    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
    [partitions-4MB-tinyuf2.csv]
